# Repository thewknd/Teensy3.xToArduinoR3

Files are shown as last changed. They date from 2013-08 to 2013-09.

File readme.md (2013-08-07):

## Teensy 3.0 to Arduino R3 breakout

## Features
- Arduino R3 Shield compatible header
- All Teensy 3.0 pins accessible 
- Battery holder for the RTC
- micro SD card holder
- Reset/Program Button
- I2C pullup resistors
- external power supply
- battery charger circuit
- two dc dc converter (CJ1117)
- XBee (pro) compatible socket
- common nRF24L01(1) module pin header
- USB to Serial converter (FT232RL) attached to Teensy Serial3
- series resistors for all arduino R3 pins
- most parts are from Seeedstudios (new) OPLV1 (for more information: http://www.seeedstudio.com/wiki/Open_parts_library)

top
top image

bottom
bottom image

## License
Except where otherwise noted, this work is licensed under 

http://creativecommons.org/licenses/by-sa/3.0/

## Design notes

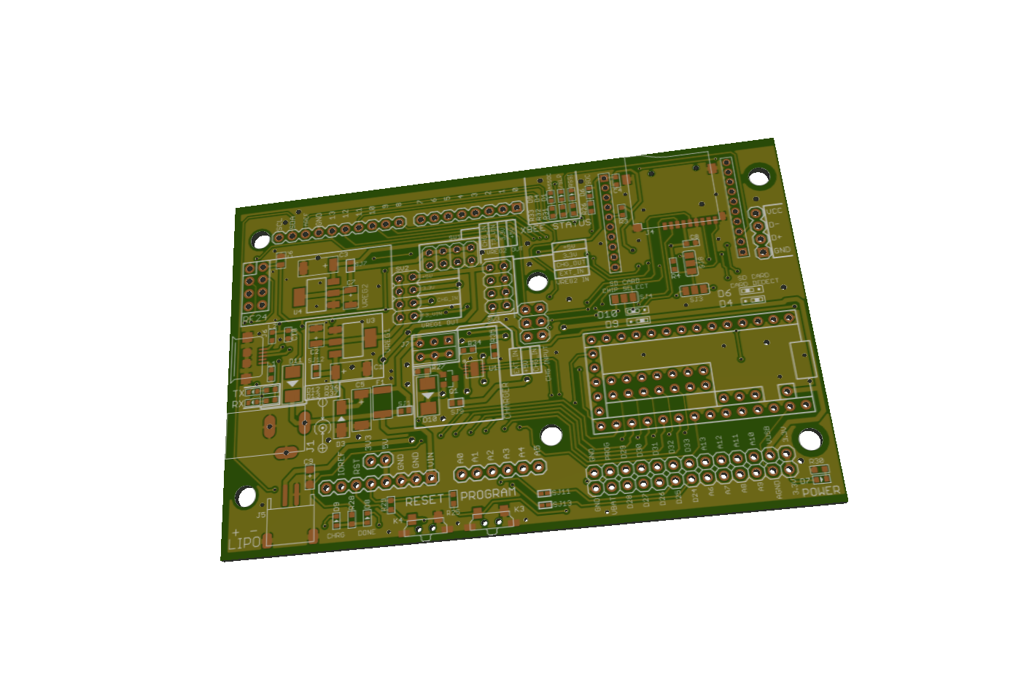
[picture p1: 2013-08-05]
top.png

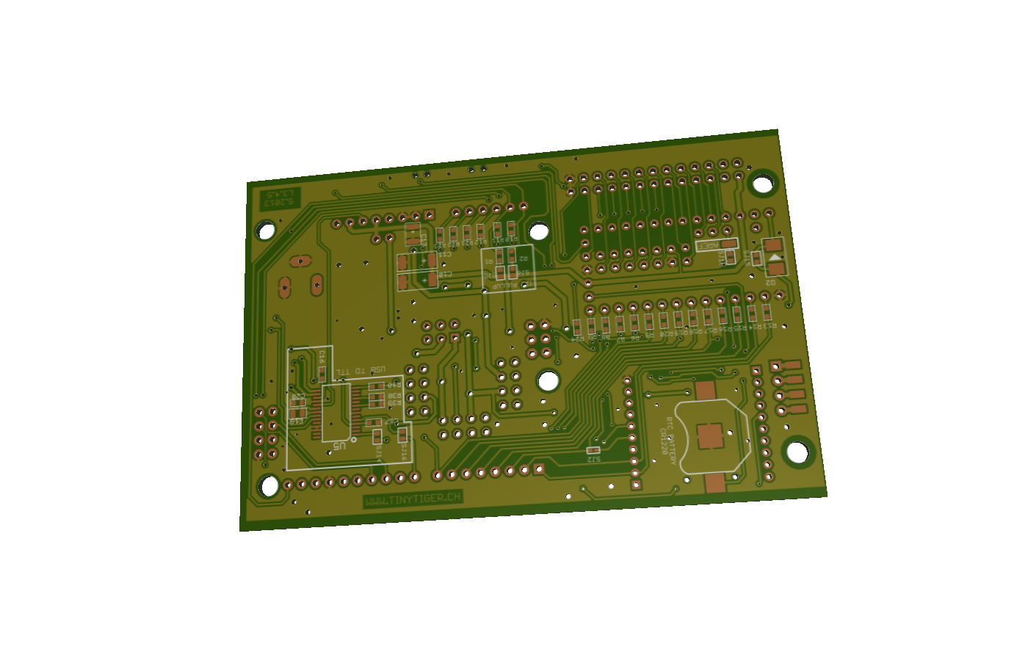
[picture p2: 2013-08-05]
bottom.png

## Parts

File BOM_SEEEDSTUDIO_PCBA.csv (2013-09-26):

OPL SKU | Qty | Parts
0440210P1 | 1 | Q1
0100020P1 | 2 | C4 C8
0100020P1 | 3 | C16 C17 C20
0900390P1 | 2 | F1 F2
0010070P1 | 20 | R5 R6 R7 R8 R9 R10 R11 R12 R13 R14 R15 R16 R17 R18 R19 R20 R21 R22 R23 R24
0011240P1 | 7 | R3 R4 R25 R29 R38 R39 R40
0100350P1 | 1 | C18
0100080P1 | 2 | C6 C19
0011090P1 | 3 | R27 R34 R35
0300040P1 | 1 | D3
0130240P1 | 2 | C2 C7
0130360P1 | 1 | C5
0130360P1 | 2 | C1 C3
0010430P1 | 1 | R28
0010600P1 | 7 | R26 R30 R31 R32 R33 R36 R37
0900120P1 | 2 | L1 L2
3100060P1 | 2 | K3 K4
1310190P1 | 1 | U4
1310170P1 | 1 | U3
1320040P1 | 1 | U1
3460510P1 | 2 | J2 J3
1720010P1 | 1 | U5
0330010P1 | 5 | D4 D5 D6 D7 D9
3410020P1 | 1 | J1
3410050P1 | 1 | J5
3300060P1 | 1 | J4
3400150P1 | 1 | J6
0330020P1 | 1 | D8
0310130P1 | 4 | D2 D10 D11 D14
0330050P1 | 3 | D1 D12 D13

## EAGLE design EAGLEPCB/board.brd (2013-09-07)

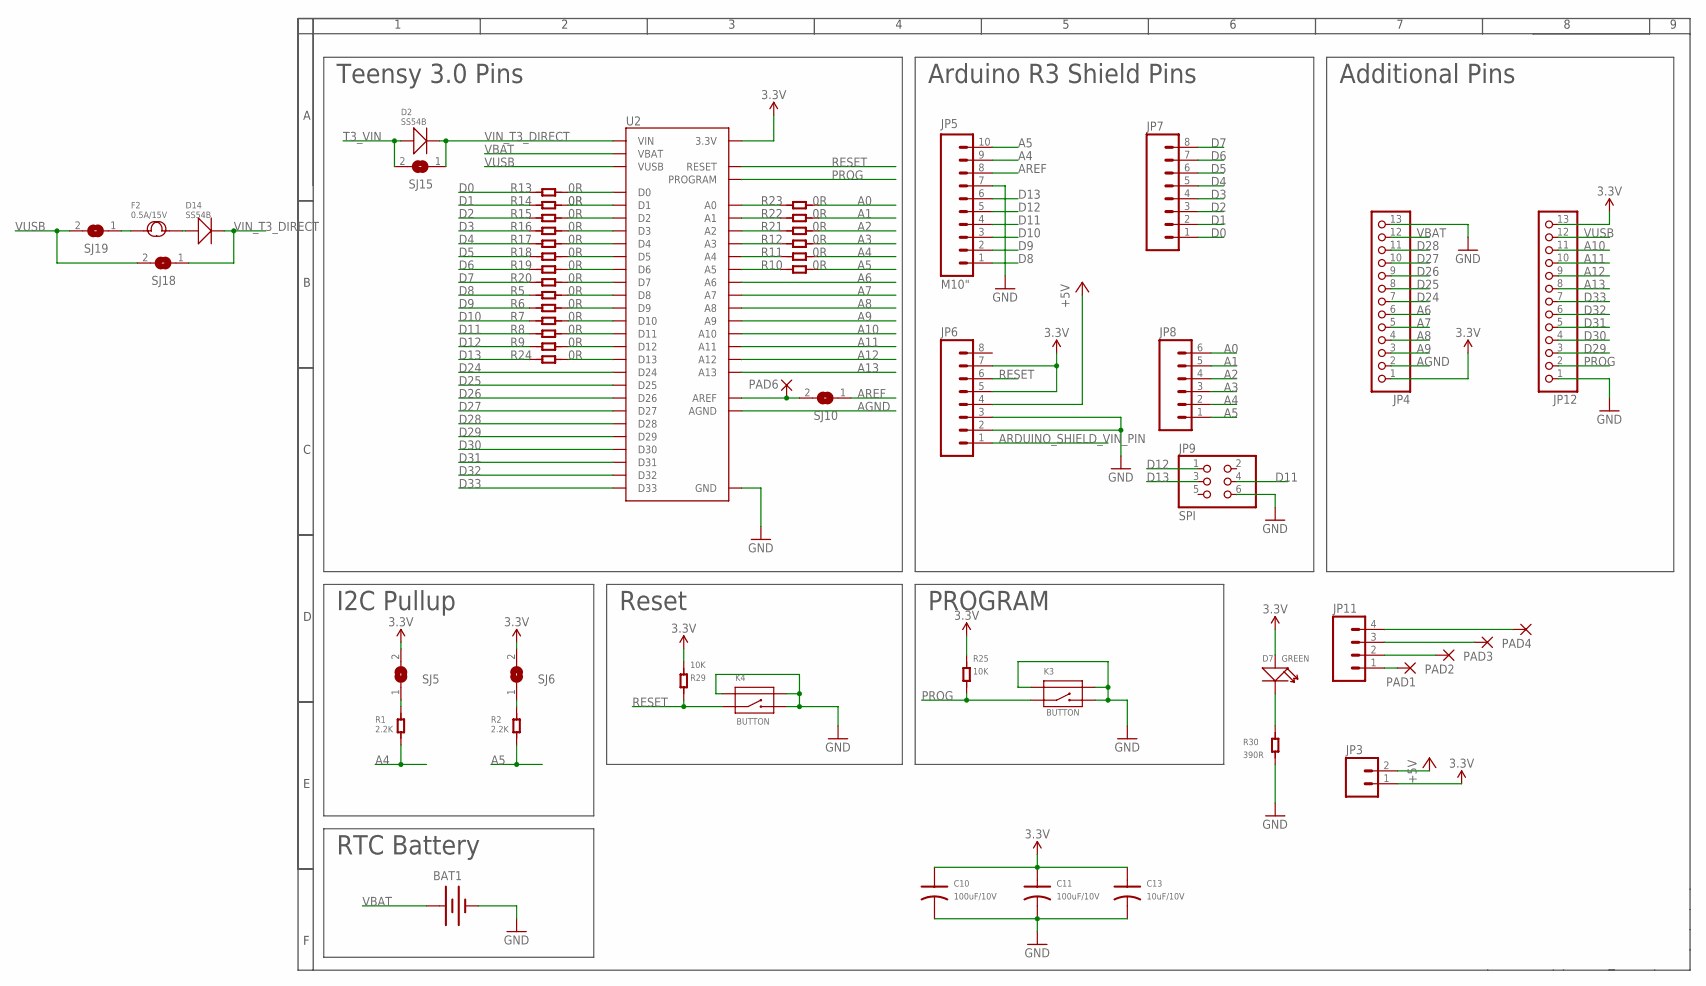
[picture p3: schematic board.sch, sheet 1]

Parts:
BAT1: BATTERY12MM; BATTCON_12MM
C10, C11: 100uF/10V; AVX-C
C13: 10uF/10V; AVX-B
D2, D14: SS54B; SMB
D7: GREEN; LED0603
F2: 0.5A/15V; F1812
JP3: M02PTH; 1X02
JP4, JP12: PINHD-1X13_BIG; 1X13-BIG
JP5: M10"; 1X10
JP6, JP7: M081X08; 1X08
JP8: M06SIP; 1X06
JP9: SPI; 2X03
JP11: M04PTH; 1X04
K3, K4: BUTTON; 4P-SMD-7.0X3.5X3.5H-90D
PAD1, PAD2, PAD3, PAD4: WIREPADSMD1,27-254; SMD1,27-2,54
PAD6: AREF; SMD1,27-2,54
R1, R2: 2.2K; R0603
R5, R6, R7, R8, R9, R10, R11, R12, R13, R14, R15, R16, R17, R18, R19, R20, R21, R22, R23, R24: 0R; R0603
R25, R29: 10K; R0603
R30: 390R; R0603
SJ5, SJ6, SJ10, SJ15, SJ18, SJ19: JUMPER_2WLARGE; JUMPER_LARGE_2WAY
U2: TEENSY3.0_ALLPINSSILK; TEENSY3.0_ALLPINS/SILK

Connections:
3.3V: C10.+ (1), C11.+ (1), C13.+ (1), D7.+, JP3.1, JP4.1, JP6.5, JP6.7, JP12.13, R25.2, R29.2, SJ5.2, SJ6.2, U2.3V3_A (3.3V), U2.3V3_B (3.3V), U2.3V3_C (3.3V); also elsewhere on the board
+5V: JP3.2, JP6.4; also elsewhere on the board
A0: JP8.6, R23.1
A1: JP8.5, R22.1
A2: JP8.4, R21.1
A3: JP8.3, R12.1
A4: JP5.9, JP8.2, R1.1, R11.1
A5: JP5.10, JP8.1, R2.1, R10.1
A6: JP4.6, U2.A6
A7: JP4.5, U2.A7
A8: JP4.4, U2.A8
A9: JP4.3, U2.A9
A10: JP12.11, U2.A10
A11: JP12.10, U2.A11
A12: JP12.9, U2.A12
A13: JP12.8, U2.A13
AGND: JP4.2, U2.AGND
ARDUINO_SHIELD_VIN_PIN: JP6.1; also elsewhere on the board
AREF: JP5.8, SJ10.1
D0: JP7.1, R13.2; also elsewhere on the board
D1: JP7.2, R14.2; also elsewhere on the board
D2: JP7.3, R15.2; also elsewhere on the board
D3: JP7.4, R16.2
D4: JP7.5, R17.2; also elsewhere on the board
D5: JP7.6, R18.2
D6: JP7.7, R19.2; also elsewhere on the board
D7: JP7.8, R20.2; also elsewhere on the board
D8: JP5.1, R5.2; also elsewhere on the board
D9: JP5.2, R6.2; also elsewhere on the board
D10: JP5.3, R7.2; also elsewhere on the board
D11: JP5.4, JP9.4, R8.2; also elsewhere on the board
D12: JP5.5, JP9.1, R9.2; also elsewhere on the board
D13: JP5.6, JP9.3, R24.2; also elsewhere on the board
D24: JP4.7, U2.D24; also elsewhere on the board
D25: JP4.8, U2.D25; also elsewhere on the board
D26: JP4.9, U2.D26
D27: JP4.10, U2.D27
D28: JP4.11, U2.D28
D29: JP12.3, U2.D29
D30: JP12.4, U2.D30
D31: JP12.5, U2.D31
D32: JP12.6, U2.D32
D33: JP12.7, U2.D33
DIRECT_AREF: PAD6.1, SJ10.2, U2.AREF
GND: BAT1.GND (-), C10.- (2), C11.- (2), C13.- (2), JP4.13, JP5.7, JP6.2, JP6.3, JP9.6, JP12.1, K3.2, K3.S1, K3.S2, K4.2, K4.S1, K4.S2, R30.1, U2.GND_A (GND), U2.GND_B (GND), U2.GND_C (GND); also elsewhere on the board
unnamed: R13.1, U2.D0
unnamed: R14.1, U2.D1
unnamed: R15.1, U2.D2
unnamed: R16.1, U2.D3
unnamed: R17.1, U2.D4
unnamed: R10.2, U2.A5
unnamed: R11.2, U2.A4
unnamed: R12.2, U2.A3
unnamed: R18.1, U2.D5
unnamed: R19.1, U2.D6
unnamed: R20.1, U2.D7
unnamed: R5.1, U2.D8
unnamed: R6.1, U2.D9
unnamed: R7.1, U2.D10
unnamed: R8.1, U2.D11
unnamed: R9.1, U2.D12
unnamed: R21.2, U2.A2
unnamed: R22.2, U2.A1
unnamed: R23.2, U2.A0
unnamed: R24.1, U2.D13
unnamed: R1.2, SJ5.1
unnamed: R2.2, SJ6.1
unnamed: D7.-, R30.2
unnamed: JP11.1, PAD1.1
unnamed: JP11.2, PAD2.1
unnamed: JP11.3, PAD3.1
unnamed: JP11.4, PAD4.1
unnamed: D14.+, F2.2
unnamed: F2.1, SJ19.1
PROG: JP12.2, K3.1, R25.1, U2.PROG (PROGRAM)
RESET: JP6.6, K4.1, R29.1, U2.RESET; also elsewhere on the board
T3_VIN: D2.+, SJ15.2; also elsewhere on the board
VBAT: BAT1.PWR@1 (+), JP4.12, U2.VBAT
VIN_T3_DIRECT: D2.-, D14.-, SJ15.1, SJ18.1, U2.VIN
VUSB: JP12.12, SJ18.2, SJ19.2, U2.VUSB; also elsewhere on the board

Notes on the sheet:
Teensy 3.0 Pins
Arduino R3 Shield Pins
I2C Pullup
Reset
Additional Pins
PROGRAM
RTC Battery

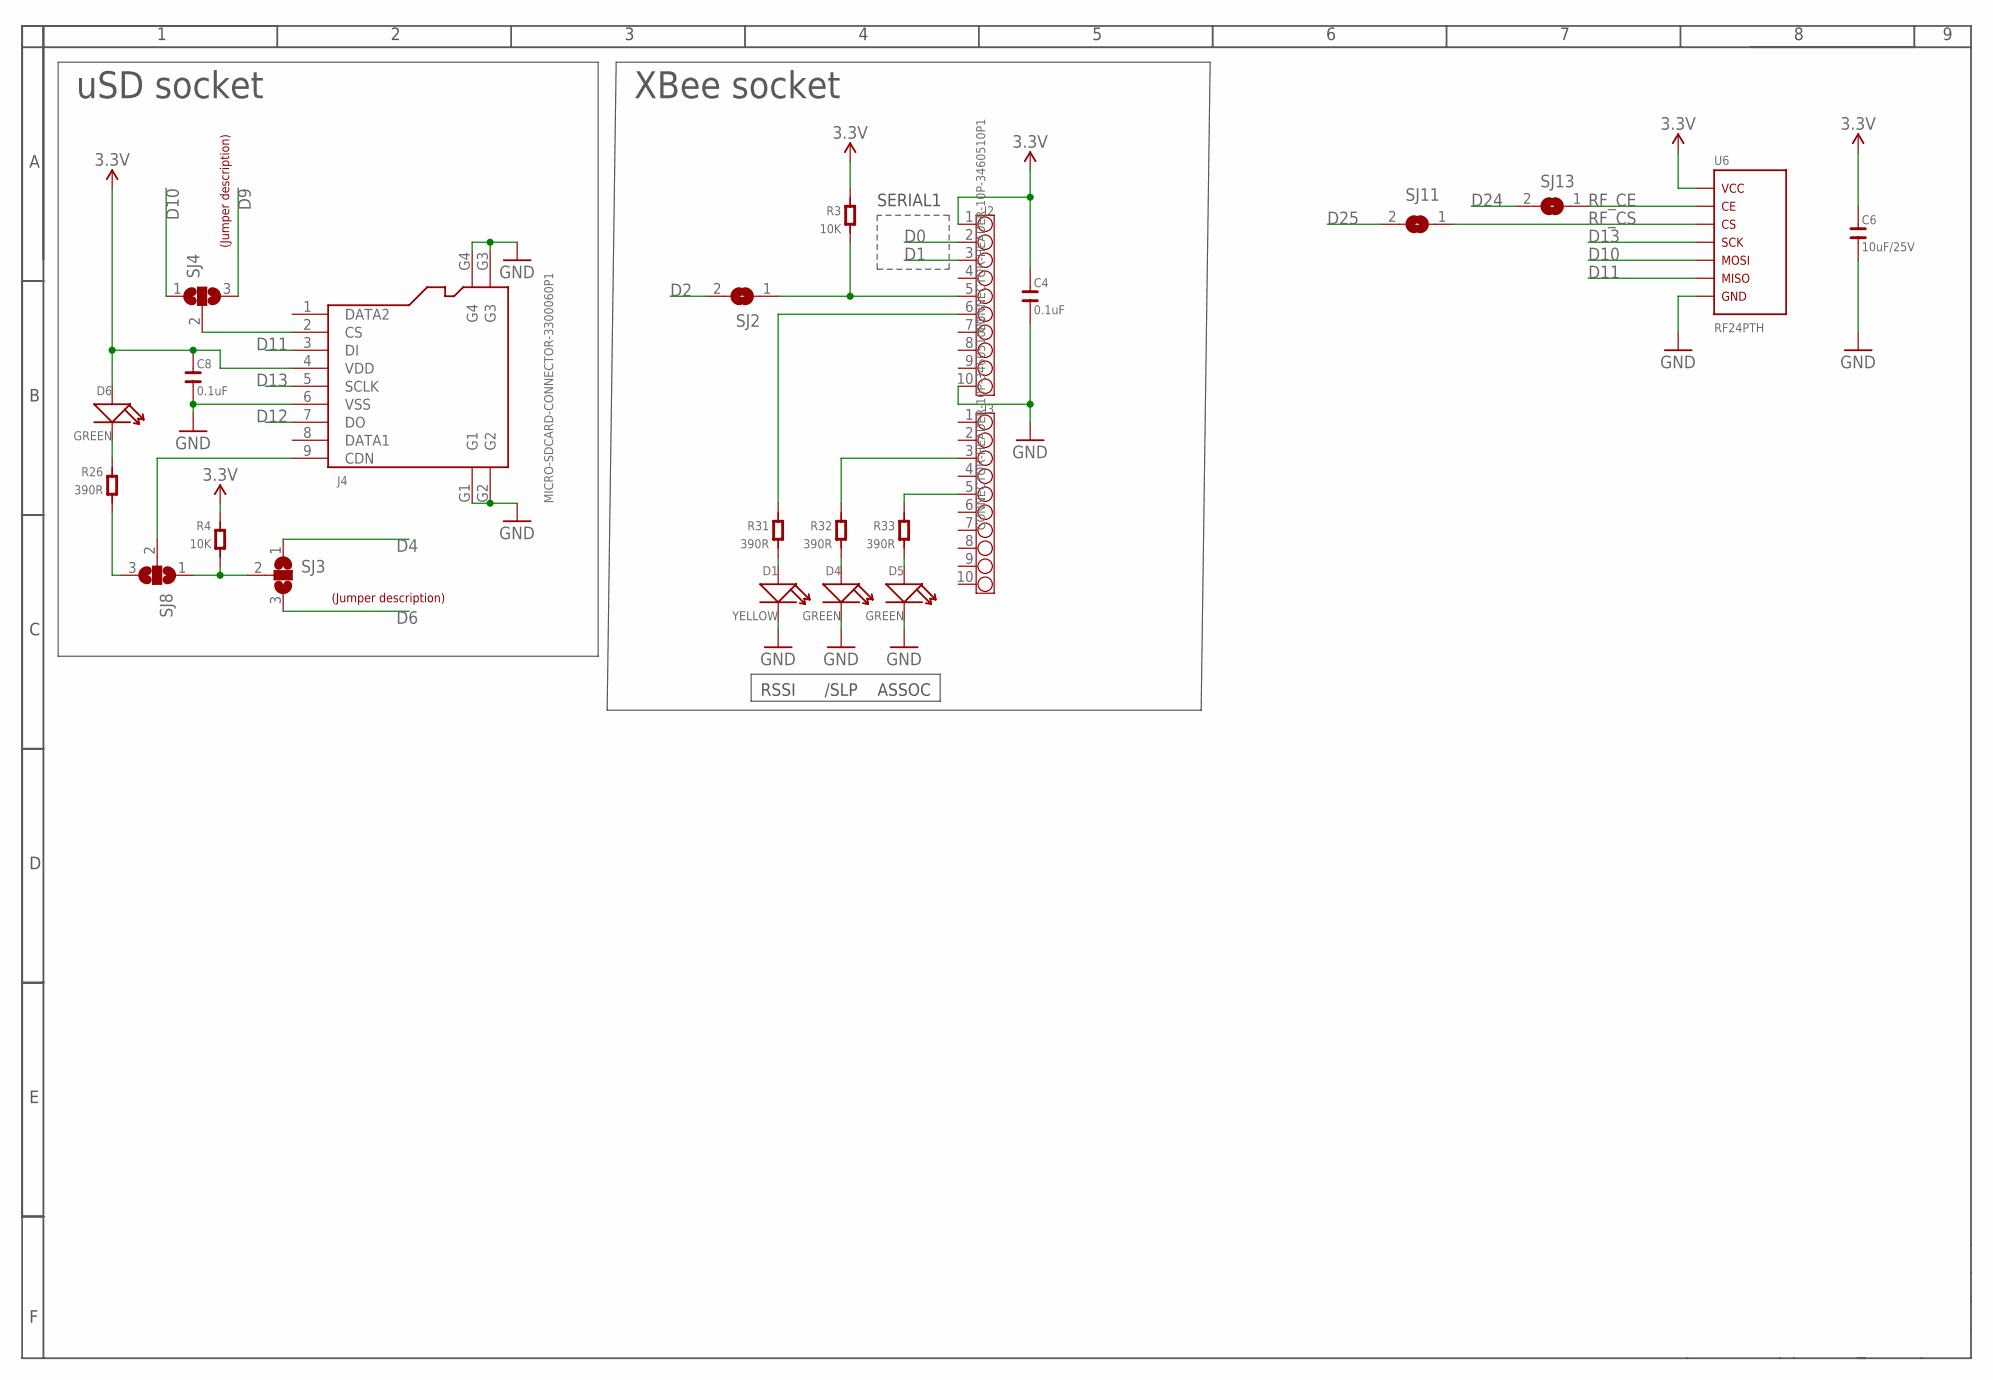
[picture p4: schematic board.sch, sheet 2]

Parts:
C4, C8: 0.1uF; C0603
C6: 10uF/25V; C0805
D1: YELLOW; LED0603
D4, D5, D6: GREEN; LED0603
J2, J3: CONNECTOR-HEADER-10P-3460510P1; 1X10P-2.0-4.3-BLUE-FEMALE
J4: MICRO-SDCARD-CONNECTOR-3300060P1; 9P-SMD-W-RING
R3, R4: 10K; R0603
R26, R31, R32, R33: 390R; R0603
SJ2, SJ11, SJ13: JUMPER_2WSMALL; JUMPER_SMALL_2WAY
SJ3, SJ4, SJ8: SJ2W; SJ_2
U6: RF24PTH; RF24
U$1, U$2: LABEL_JUMPER_1X3; JUMP3_DESC

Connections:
3.3V: C4.2, C6.2, C8.2, D6.+, J2.1, J4.4 (VDD), R3.2, R4.1, U6.VCC; also elsewhere on the board
D0: J2.2; also elsewhere on the board
D1: J2.3; also elsewhere on the board
D2: SJ2.2; also elsewhere on the board
D4: SJ3.1; also elsewhere on the board
D6: SJ3.3; also elsewhere on the board
D9: SJ4.3; also elsewhere on the board
D10: SJ4.1, U6.MOSI; also elsewhere on the board
D11: J4.3 (DI), U6.MISO; also elsewhere on the board
D12: J4.7 (DO); also elsewhere on the board
D13: J4.5 (SCLK), U6.SCK; also elsewhere on the board
D24: SJ13.2; also elsewhere on the board
D25: SJ11.2; also elsewhere on the board
DFGDFG: J2.5, R3.1, SJ2.1
ESDASGGGG: R4.2, SJ3.2, SJ8.1
GND: C4.1, C6.1, C8.1, D1.-, D4.-, D5.-, J2.10, J4.6 (VSS), J4.G1, J4.G2, J4.G3, J4.G4, U6.GND; also elsewhere on the board
unnamed: J3.5, R33.2
unnamed: D1.+, R31.1
unnamed: D4.+, R32.1
unnamed: J3.3, R32.2
unnamed: D5.+, R33.1
unnamed: R26.1, SJ8.3
unnamed: J2.6, R31.2
unnamed: D6.-, R26.2
unnamed: J4.9 (CDN), SJ8.2
unnamed: J4.2 (CS), SJ4.2
RF_CE: SJ13.1, U6.CE
RF_CS: SJ11.1, U6.CS

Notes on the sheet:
uSD socket
XBee socket
SERIAL1
ASSOC
/SLP
RSSI

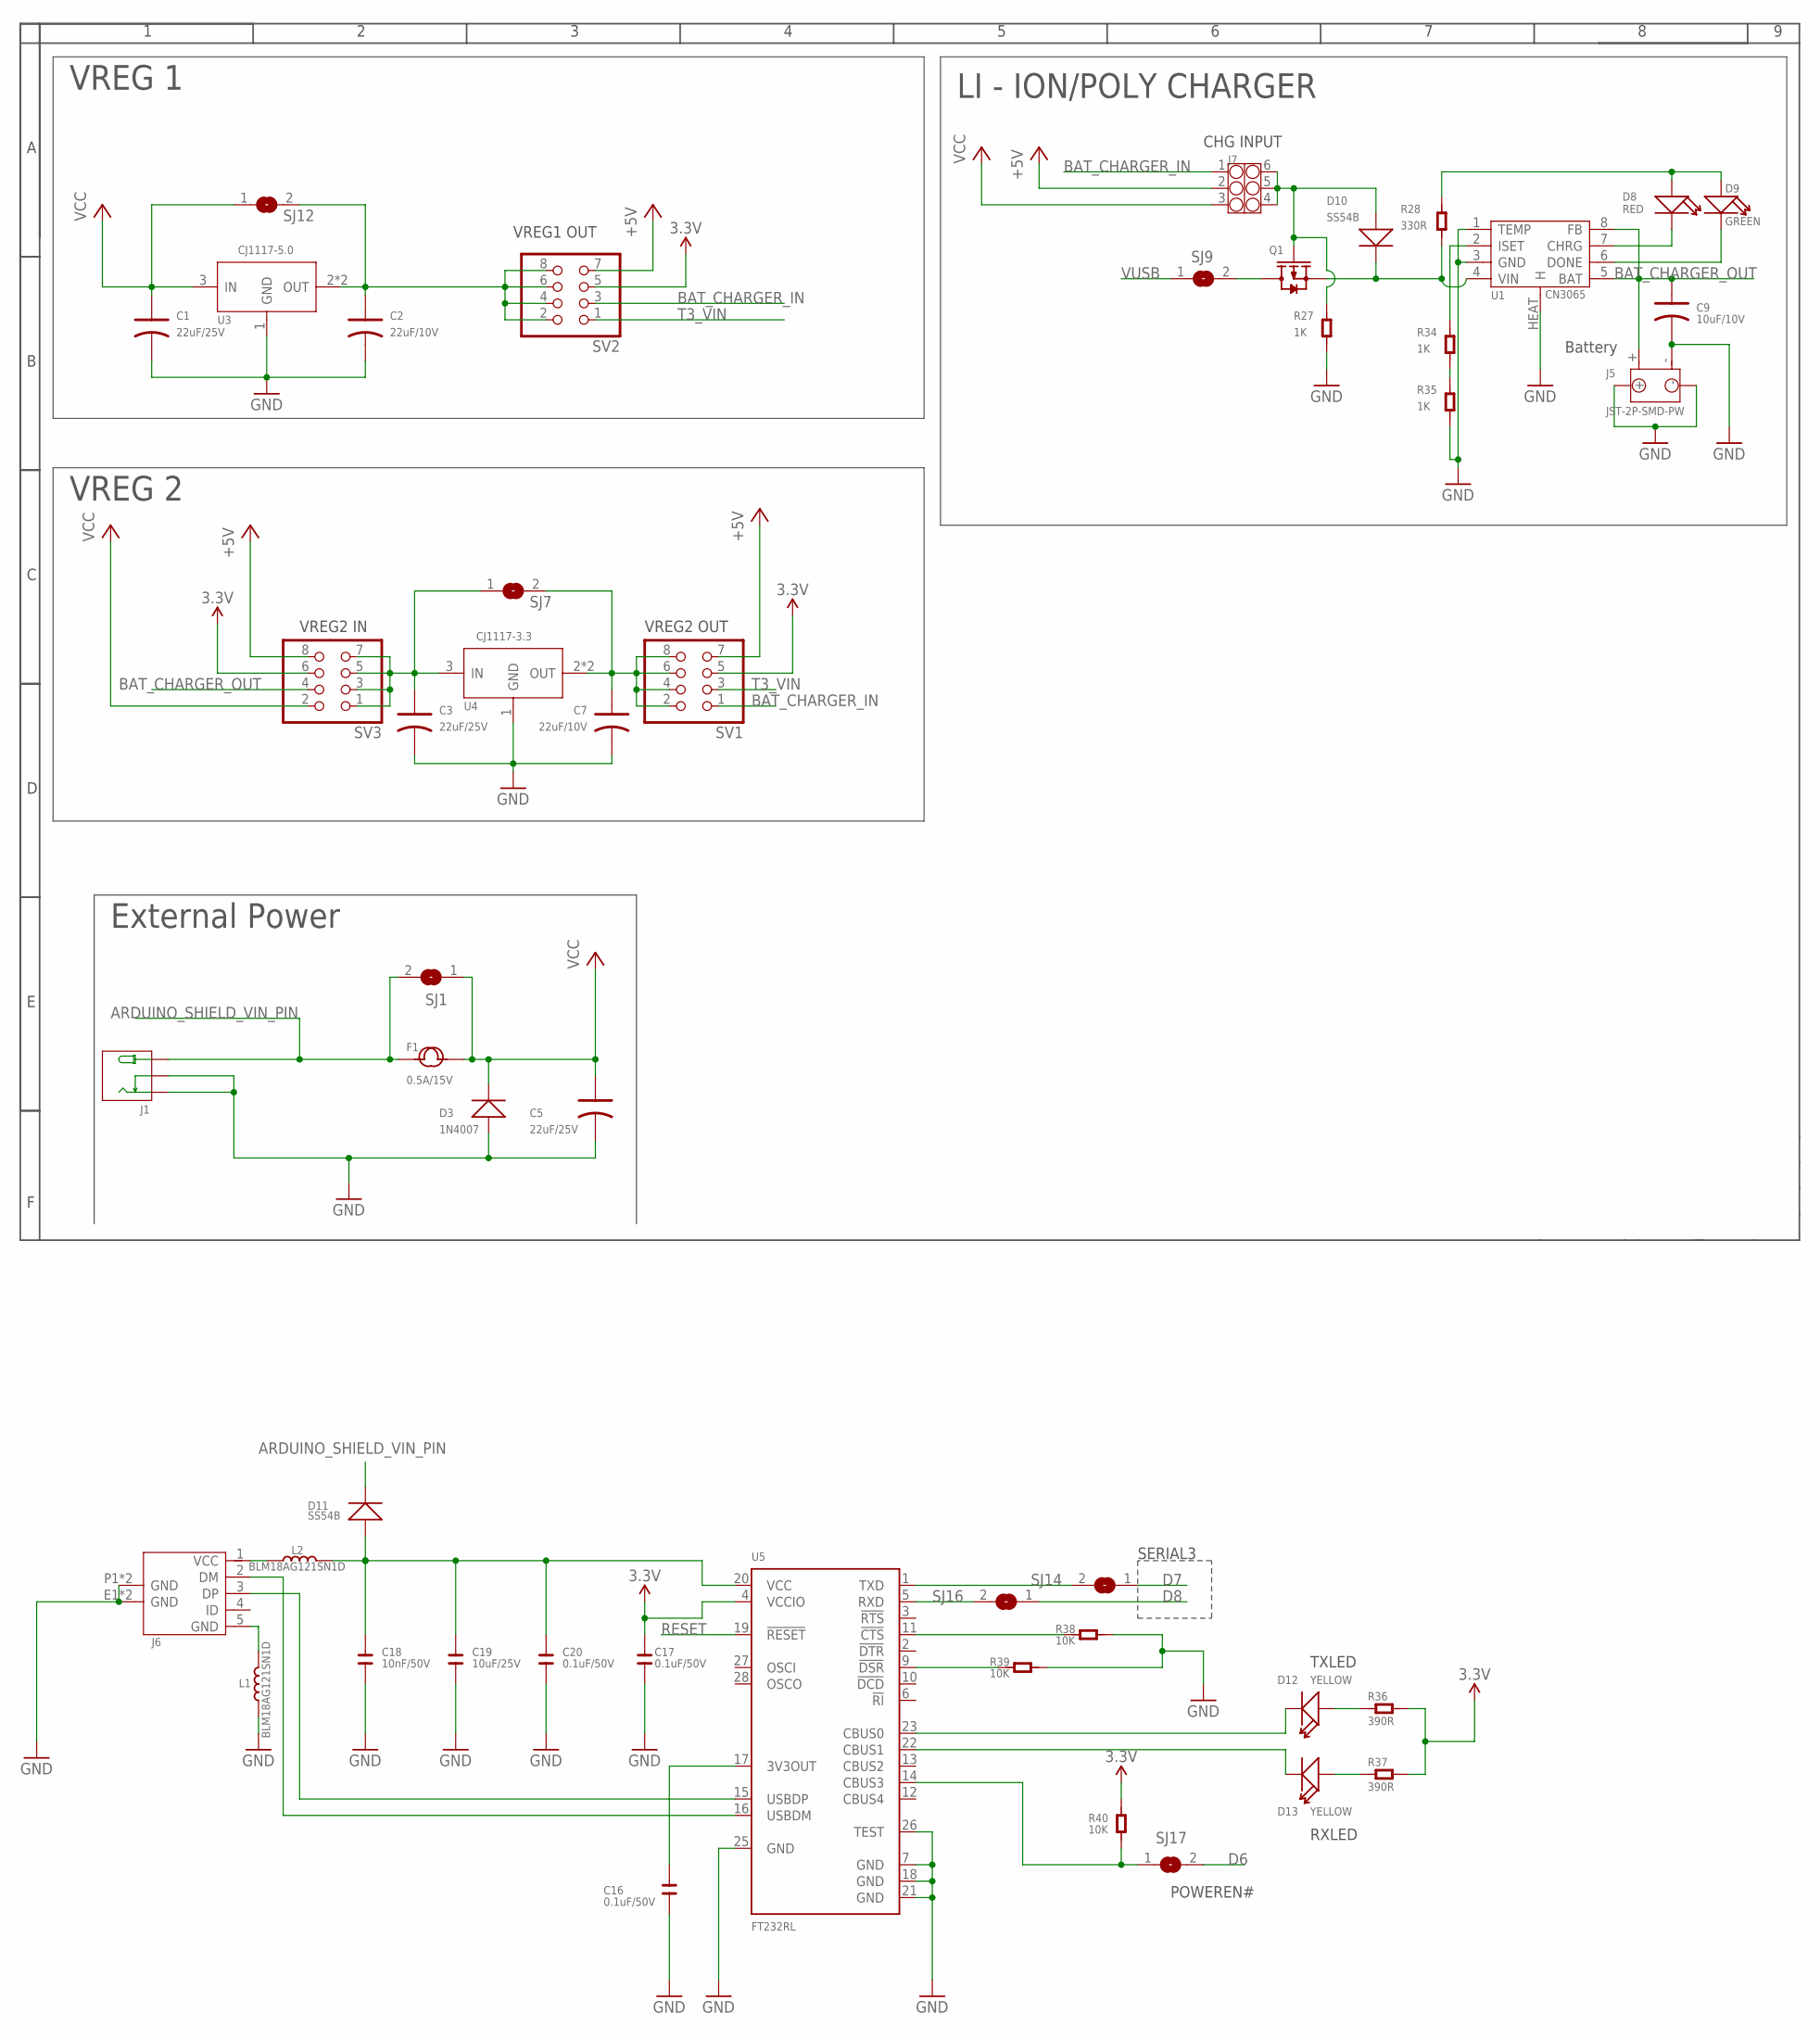
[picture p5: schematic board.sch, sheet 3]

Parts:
C1, C3: 22uF/25V; AVX-C; MPN TAJC226K025RNJ
C2, C7: 22uF/10V; AVX-B
C5: 22uF/25V; AVX-C
C9: 10uF/10V; AVX-A
C16, C17, C20: 0.1uF/50V; C0603
C18: 10nF/50V; C0603
C19: 10uF/25V; C0805
D3: 1N4007; DO-214AC
D8: RED; LED0603
D9: GREEN; LED0603
D10, D11: SS54B; SMB
D12, D13: YELLOW; LED0603
F1: 0.5A/15V; F1812
J1: JACK-DC-3P-3410020P1; PW-3P-2.1
J5: JST-2P-SMD-PW; 2P-SMD-2.0-90D
J6: MICRO-USB-5P-3400150P1; B-SMD-5P
J7: CONNECTOR-HEADER-2X3P-3460180P1; 2X3P-2.54-2.54-11.6-3.0-BLACK-MALE
L1, L2: BLM18AG121SN1D; L0603
Q1: MOSFET-P-0440210P1; SOT23
R27, R34, R35: 1K; R0603
R28: 330R; R0603
R36, R37: 390R; R0603
R38, R39, R40: 10K; R0603
SJ1, SJ7, SJ9, SJ12, SJ14, SJ16, SJ17: JUMPER_2WLARGE; JUMPER_LARGE_2WAY
SV1, SV2, SV3: PINHD-2X4_2.54; 2X04
U1: CN3065; DFN8
U3: CJ1117-5.0; SOT223
U4: CJ1117-3.3; SOT223
U5: FT232RL; SSOP28

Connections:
3.3V: C17.1, R36.2, R37.2, R40.2, SV1.5, SV2.5, SV3.6, U5.4 (VCCIO); also elsewhere on the board
+5V: J7.2, SV1.7, SV2.7, SV3.8; also elsewhere on the board
ARDUINO_SHIELD_VIN_PIN: D11.-, F1.1, J1.+, SJ1.2; also elsewhere on the board
BAT_CHARGER_IN: J7.1, SV1.1, SV2.3
BAT_CHARGER_OUT: C9.+ (1), J5.+, SV3.4, U1.5 (BAT), U1.8 (FB)
D6: SJ17.2; also elsewhere on the board
D7: SJ14.1; also elsewhere on the board
D8: SJ16.1; also elsewhere on the board
GND: C1.- (2), C2.- (2), C3.- (2), C5.- (2), C7.- (2), C9.- (2), C16.2, C17.2, C18.2, C19.2, C20.2, D3.1 (+), J1.-1 (-), J1.-2 (CDN), J5.3, J5.4, J5.-, J6.E1 (GND), J6.E2 (GND), J6.P1 (GND), J6.P2 (GND), L1.1, R27.1, R35.1, R38.2, R39.2, U1.1 (TEMP), U1.3 (GND), U1.HEAT (H), U3.1 (GND), U4.1 (GND), U5.7 (GND), U5.18 (GND), U5.21 (GND), U5.25 (GND), U5.26 (TEST); also elsewhere on the board
unnamed: C3.+ (1), SJ7.1, SV3.1, SV3.3, SV3.5, SV3.7, U4.3 (IN)
unnamed: C7.+ (1), SJ7.2, SV1.2, SV1.4, SV1.6, SV1.8, U4.2 (OUT), U4.TER (OUT)
unnamed: D10.-, Q1.2 (S), R28.1, U1.4 (VIN)
unnamed: C18.1, C19.1, C20.1, D11.+, L2.2, U5.20 (VCC)
unnamed: D8.-, U1.7 (CHRG)
unnamed: D9.-, U1.6 (DONE)
unnamed: D8.+, D9.+, R28.2
unnamed: R34.2, U1.2 (ISET)
unnamed: Q1.3 (D), SJ9.2
unnamed: J6.2 (DM), U5.16 (USBDM)
unnamed: J6.3 (DP), U5.15 (USBDP)
unnamed: R38.1, U5.11 (!CTS)
unnamed: R39.1, U5.9 (!DSR)
unnamed: SJ14.2, U5.1 (TXD)
unnamed: C2.+ (1), SJ12.2, SV2.2, SV2.4, SV2.6, SV2.8, U3.2 (OUT), U3.TER (OUT)
unnamed: SJ16.2, U5.5 (RXD)
unnamed: D12.-, U5.23 (CBUS0)
unnamed: R40.1, SJ17.1, U5.14 (CBUS3)
unnamed: D13.-, U5.22 (CBUS1)
unnamed: R34.1, R35.2
unnamed: C16.1, U5.17 (3V3OUT)
unnamed: D12.+, R36.1
unnamed: D13.+, R37.1
unnamed: J6.5 (GND), L1.2
unnamed: J6.1 (VCC), L2.1
NET45456: D10.+, J7.4, J7.5, J7.6, Q1.1 (G), R27.2
RESET: U5.19 (!RESET); also elsewhere on the board
T3_VIN: SV1.3, SV2.1; also elsewhere on the board
VCC: C1.+ (1), C5.+ (1), D3.2 (-), F1.2, J7.3, SJ1.1, SJ12.1, SV3.2, U3.3 (IN)
VUSB: SJ9.1; also elsewhere on the board

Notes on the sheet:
External Power
VREG 2
VREG 1
LI - ION/POLY CHARGER
SERIAL3
TXLED
RXLED
VREG1 OUT
VREG2 OUT
VREG2 IN
CHG INPUT
Battery
POWEREN#

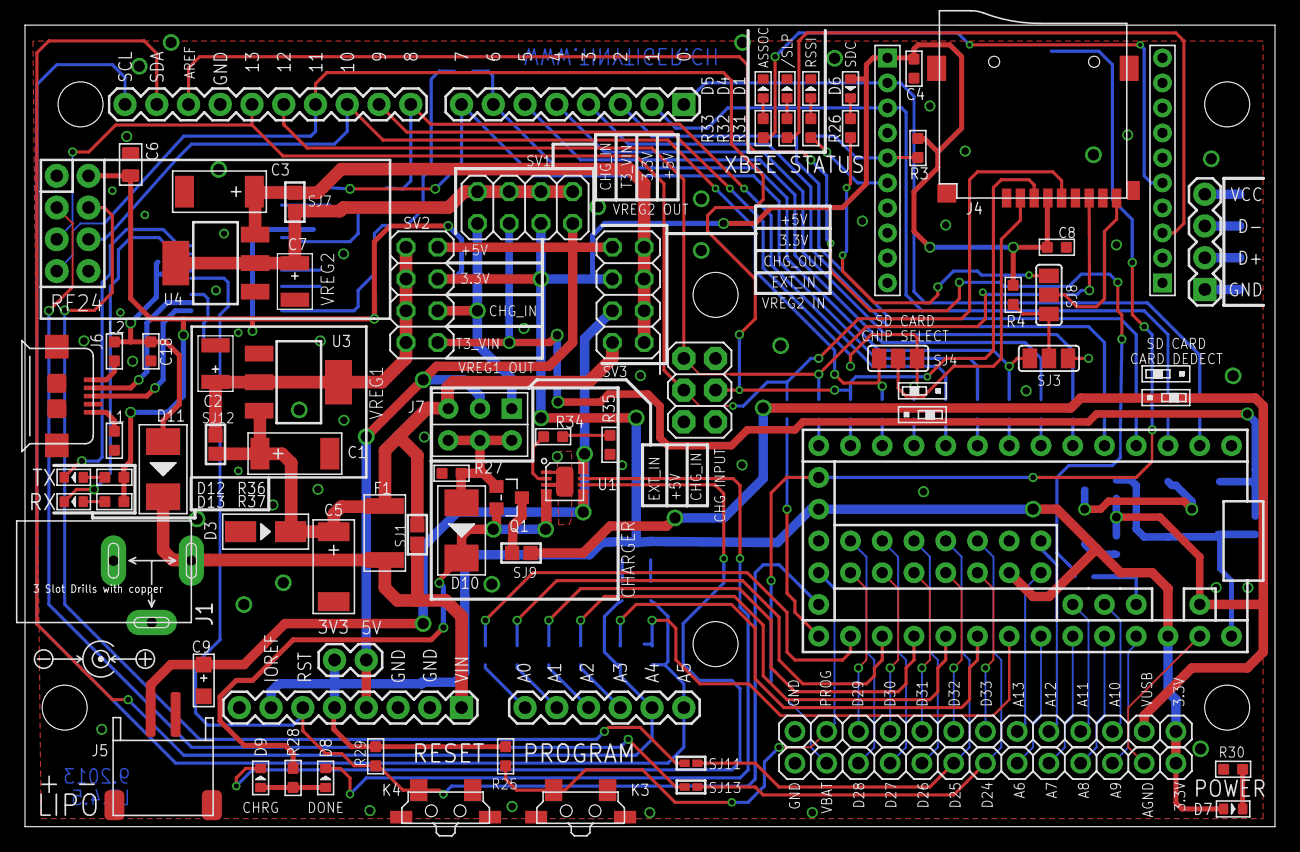
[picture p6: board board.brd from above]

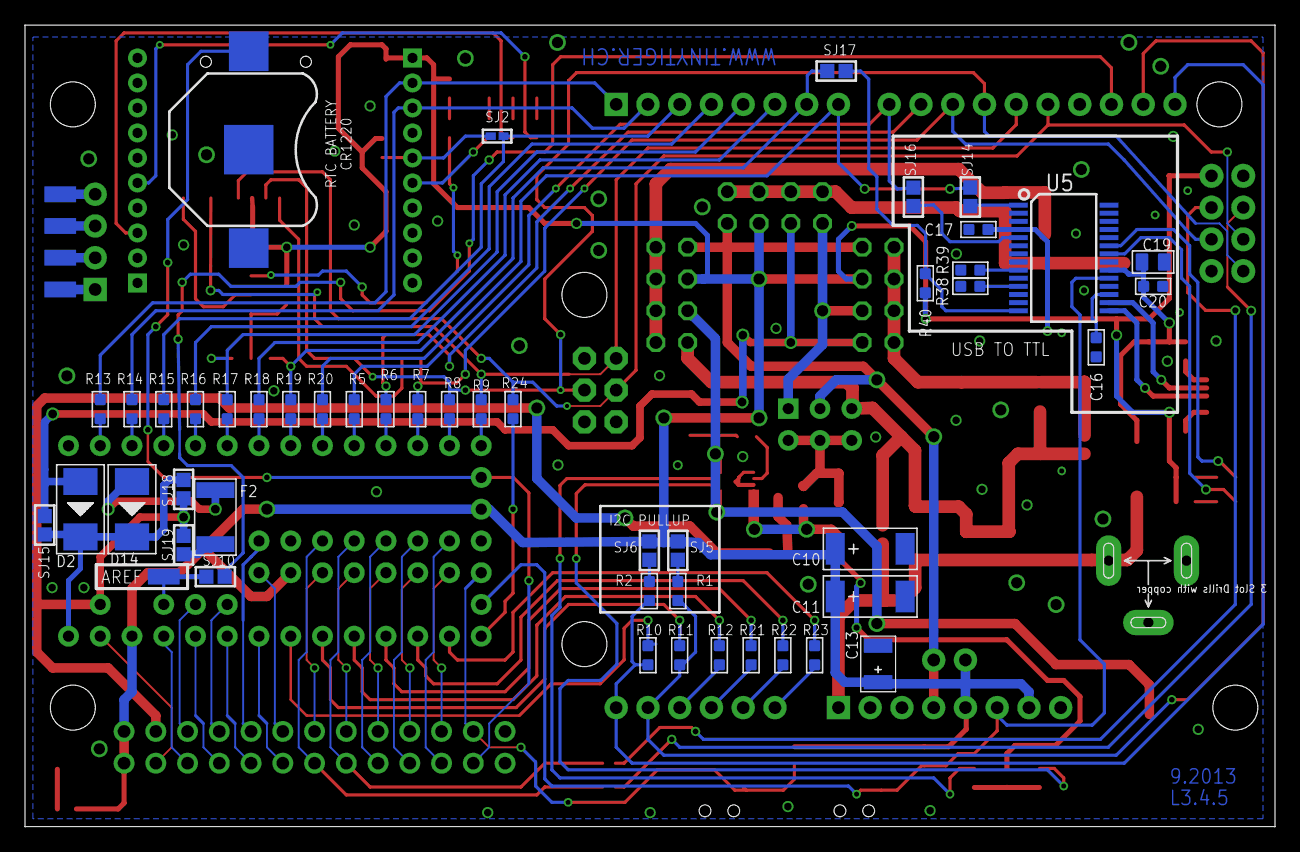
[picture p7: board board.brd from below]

Board: 2 copper layers, 100.0 x 64.1 mm, 130 parts (52 on the bottom side), 123 nets.

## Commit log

2012-11-18 added readme
    [ttab.sch]
2012-11-20 new board
    new board: teensy 3.0 to breadboard adapter
    [100003392.GBL, 100003392.GBO, 100003392.GBS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]
2012-11-20 update breadboard adapter
    [dip.GTO]
2012-11-21 new teensy 3.0 to arduino R3 board
    [100003392.GBL, 100003392.GBO, 100003392.GBS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]
2012-11-22 update Arduino R3 board
    [board.brd, board.sch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]
2012-11-24 update: -Arduino R3 pcb - breadboard pcb
    [board.brd, board.sch, dip.brd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]
2012-11-24 added i2c eeprom, sdcard
    [board.brd, board.sch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]
2012-12-08 Version 3 final
    [board.brd, board.sch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]
2012-12-19 V3-2: fixed several bugs
    [board.brd, board.sch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]
2013-08-05 inital commit for V5
    [board.brd, board.sch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]
2013-08-07 upload BOM
    [BOM_SEEEDSTUDIO_PCBA.csv]
2013-09-07 update design
    [BOM_SEEEDSTUDIO_PCBA.csv, board.brd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]

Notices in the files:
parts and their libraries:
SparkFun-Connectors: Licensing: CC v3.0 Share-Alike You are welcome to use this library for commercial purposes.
